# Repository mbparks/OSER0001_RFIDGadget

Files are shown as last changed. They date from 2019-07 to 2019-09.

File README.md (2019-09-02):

View this project on [CADLAB.io](https://cadlab.io/project/2087). 

# Open Source Escape Room Gadget #0001: RFID Puzzle
One of the more nifty puzzles of a great escape room is having to find objects and place them at an exact spot. Say three different candlesticks on a fireplace mantle in a specific order.

RFID tags are a great way to achieve this goal. Embedding RFID tags in the objects and RFID reader at the location the objects are to be placed.

We're building a great solution for just this puzzle concept.

The hardware includes an Arduino Uno, custom Uno shield, and dedicate PCB for 1 to 4 RFID readers to connect. While the software provided is for PN532 RFID readers using SPI communications, the hardware could be used for any RFID reader that communicates back to the microcontroller over SPI. The shield also provides for digital and analog outputs when the puzzle is unlocked. Say to activate a relay. Also an external reset is provided so escape room operators can reset the puzzle from afar.

The software requires just a few small tweaks to change from 1 to 4 RFID readers.

The source code is provided for free on GitHub and an upcoming guidebook will be available on our Gumroad store for around $5 to $10.

This design is provided as-is and no guarantees are offered. Use at your own risk.

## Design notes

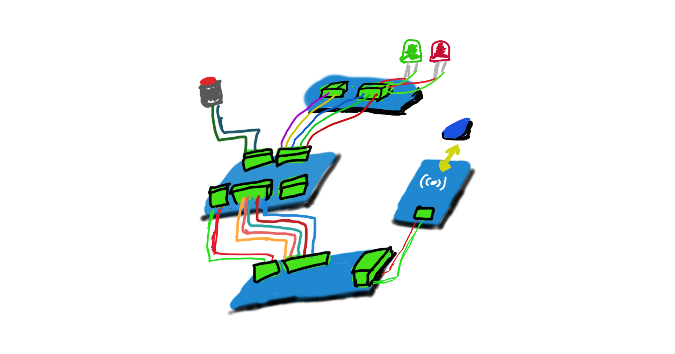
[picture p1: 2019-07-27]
Documentation/OSER0001_RFID_Concept1.png

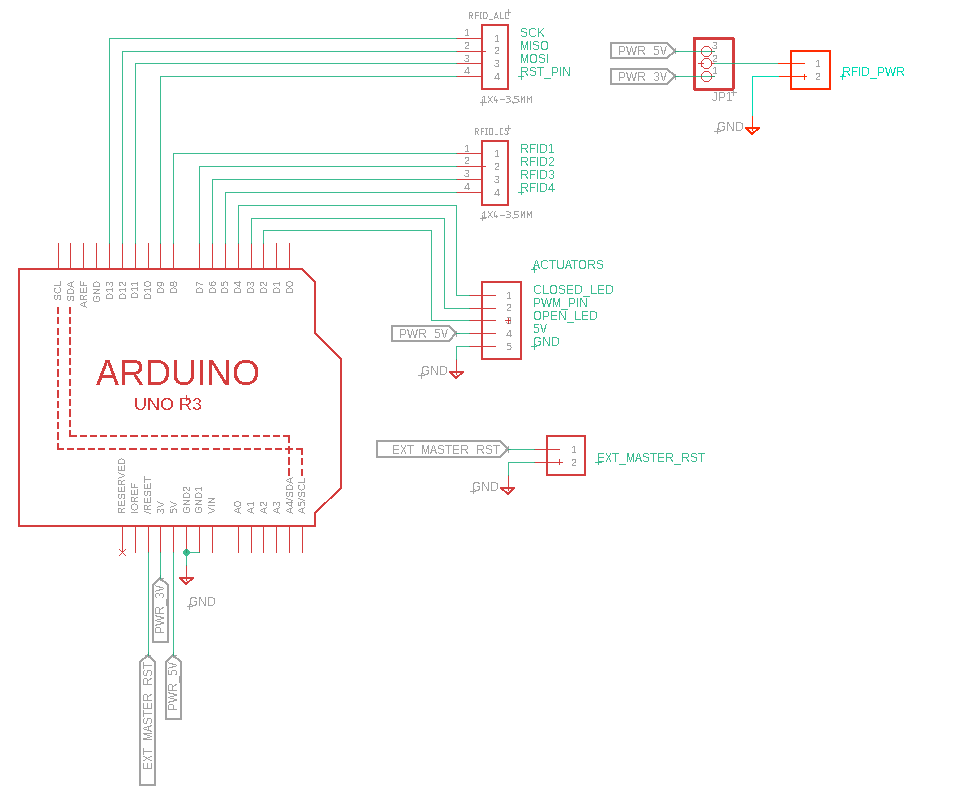
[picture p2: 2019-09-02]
Documentation/OSER0001_RFID_UnoShield_Schematic.png

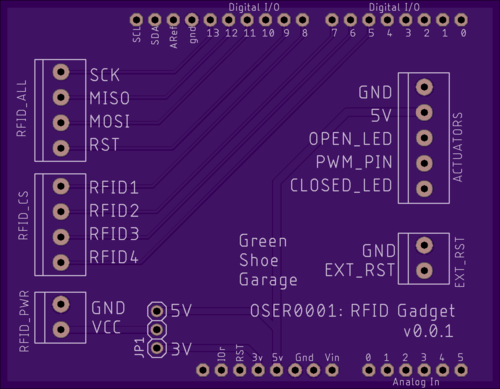
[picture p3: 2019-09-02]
Documentation/OSER0001_RFID_UnoShield_Top.png

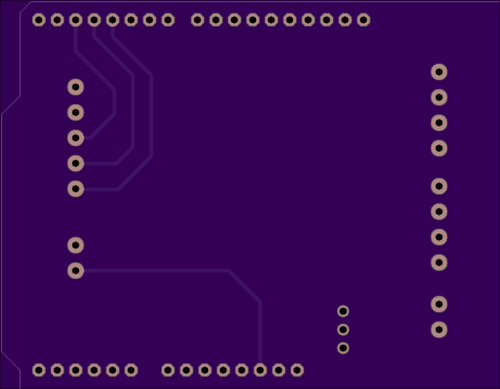
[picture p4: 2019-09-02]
Documentation/OSER0001_RFID_UnoShield_Bottom.png

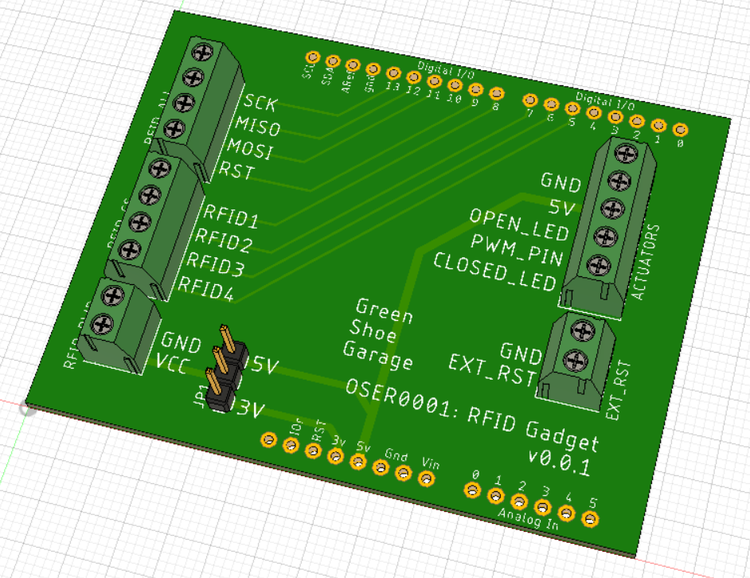
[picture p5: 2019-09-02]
Documentation/OSER0001_RFID_UnoShield_BRD3D.png

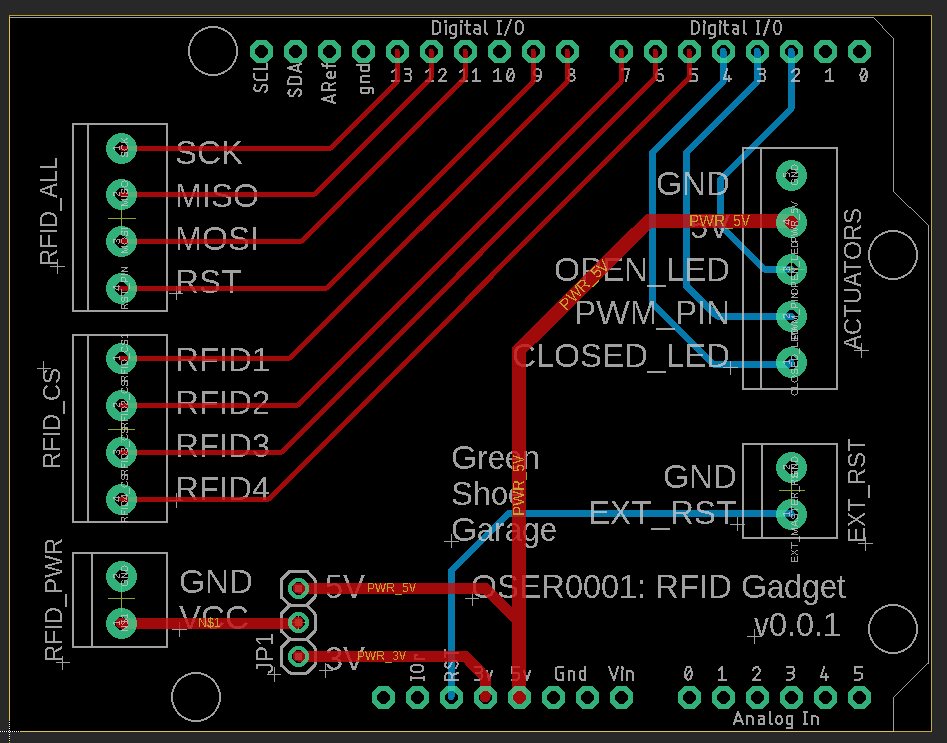
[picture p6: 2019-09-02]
Documentation/OSER0001_RFID_UnoShield_BRD.png

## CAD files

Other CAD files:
3D/OSER0001_RFID_UnoShield/OSER0001_RFID_UnoShieldPCBA/OSER_RFID_UnoShield v1.f3d

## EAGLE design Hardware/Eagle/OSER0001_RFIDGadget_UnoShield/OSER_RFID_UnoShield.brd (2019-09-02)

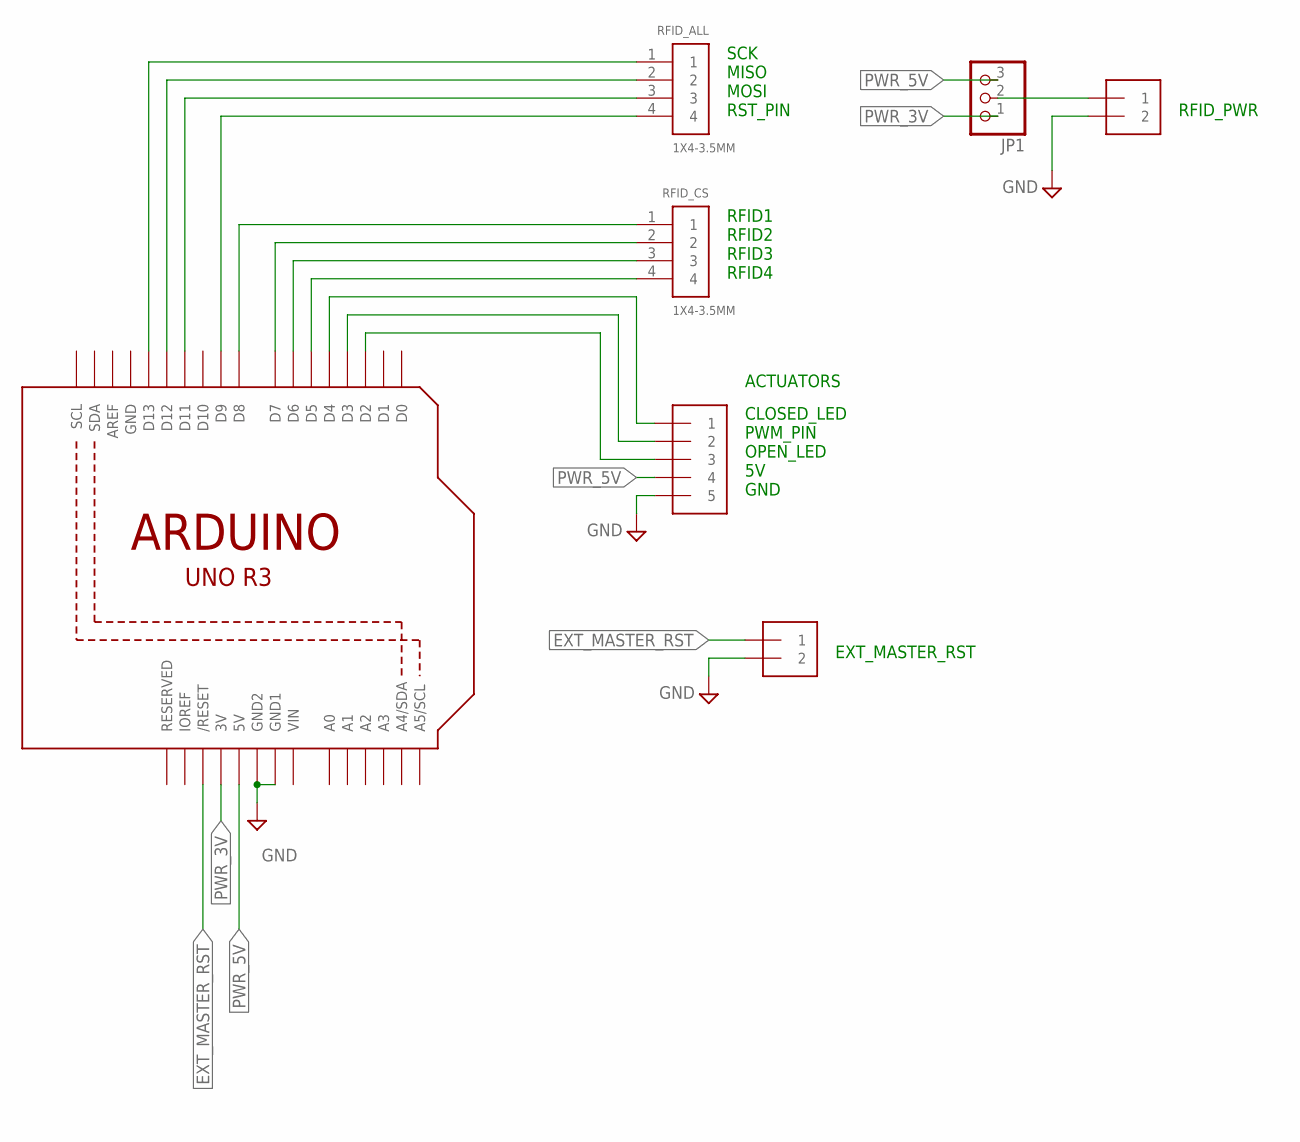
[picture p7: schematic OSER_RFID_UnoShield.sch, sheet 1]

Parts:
ACTUATORS: 1X5; 1X05-3.5MM
EXT_RST: 1X2-3.5MM
JP1: PINHD-1X3; 1X03
RFID_ALL: 1X4-3.5MM; 1X04-3.5MM
RFID_CS: 1X4-3.5MM; 1X04-3.5MM
RFID_PWR: 1X2-3.5MM
U1: ARDUINOR3-BPLACE

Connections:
CLOSED_LED: ACTUATORS.1, U1.D4
EXT_MASTER_RST: EXT_RST.1, U1.RESET (/RESET)
GND: ACTUATORS.5, EXT_RST.2, RFID_PWR.2, U1.GND, U1.GND1, U1.GND2
MISO: RFID_ALL.2, U1.D12
MOSI: RFID_ALL.3, U1.D11
unnamed: JP1.2, RFID_PWR.1
OPEN_LED: ACTUATORS.3, U1.D2
PWM_PIN: ACTUATORS.2, U1.D3
PWR_3V: JP1.1, U1.3V
PWR_5V: ACTUATORS.4, JP1.3, U1.5V
RFID2_CS: RFID_CS.2, U1.D7
RFID3_CS: RFID_CS.3, U1.D6
RFID4_CS: RFID_CS.4, U1.D5
RFID_CS1: RFID_CS.1, U1.D8
RST_PIN: RFID_ALL.4, U1.D9
SCK: RFID_ALL.1, U1.D13
VIN: U1.VIN

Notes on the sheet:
SCK MISO MOSI RST_PIN
RFID1 RFID2 RFID3 RFID4
RFID_PWR
EXT_MASTER_RST
CLOSED_LED PWM_PIN OPEN_LED 5V GND
ACTUATORS

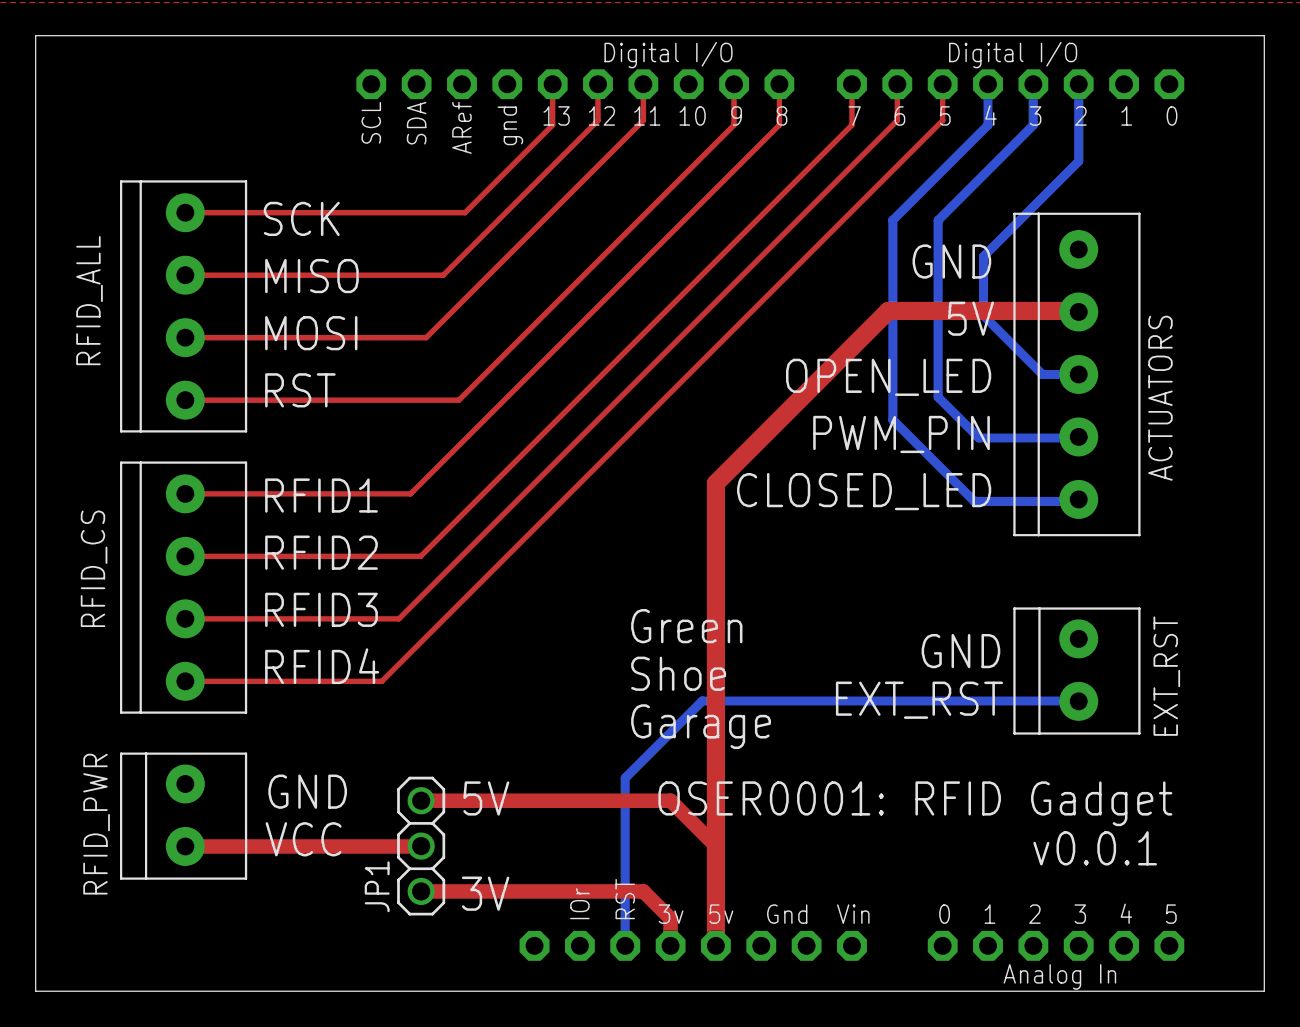
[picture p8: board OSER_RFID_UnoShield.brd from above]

Board: 2 copper layers, 68.8 x 53.5 mm, 7 parts (0 on the bottom side), 16 nets.

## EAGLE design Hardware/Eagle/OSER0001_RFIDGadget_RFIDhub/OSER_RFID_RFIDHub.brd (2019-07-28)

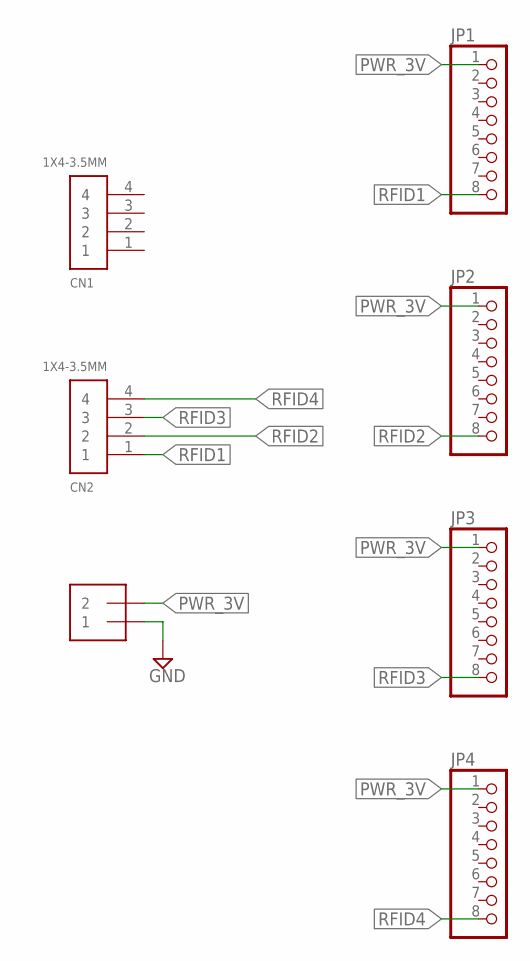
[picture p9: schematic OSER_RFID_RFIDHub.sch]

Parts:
CN1, CN2: 1X4-3.5MM; 1X04-3.5MM
J1: 1X2-3.5MM
JP1, JP2, JP3, JP4: PINHD-1X8BIG; 1X08-BIG

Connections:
GND: J1.1
PWR_3V: J1.2, JP1.1, JP2.1, JP3.1, JP4.1
RFID1: CN2.1, JP1.8
RFID2: CN2.2, JP2.8
RFID3: CN2.3, JP3.8
RFID4: CN2.4, JP4.8

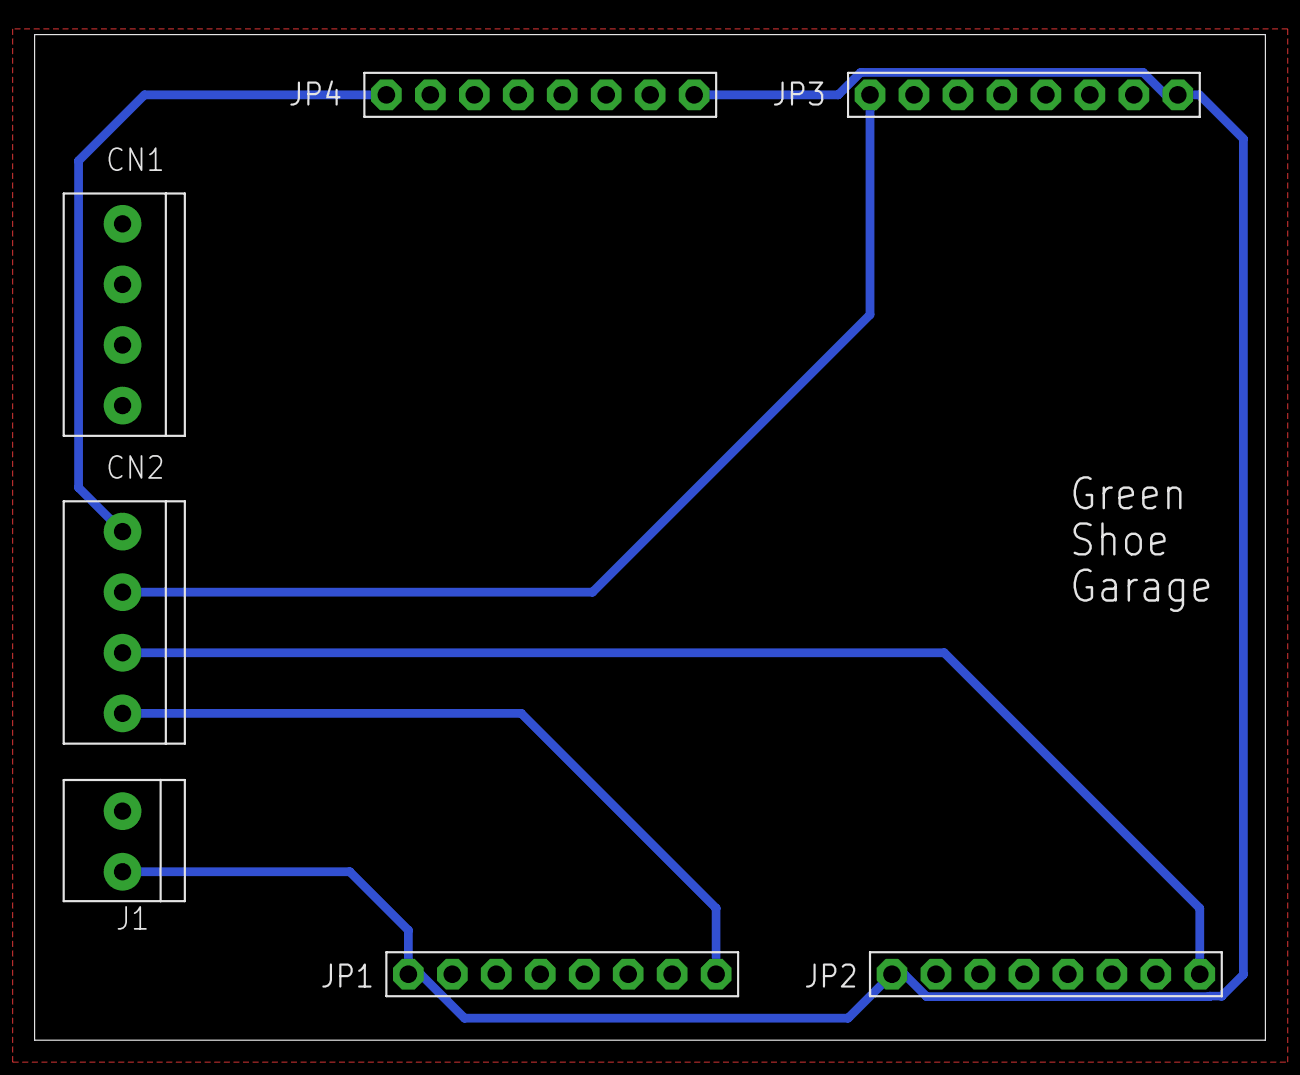
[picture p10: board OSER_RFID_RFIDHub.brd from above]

Board: 2 copper layers, 71.1 x 58.1 mm, 7 parts (0 on the bottom side), 5 nets.

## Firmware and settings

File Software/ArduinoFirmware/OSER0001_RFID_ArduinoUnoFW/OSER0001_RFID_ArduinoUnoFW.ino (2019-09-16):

/**************************************************************************
  File:    OSER0001_RFID_ArduinoUnoFW
  Author:  mbparks
  Date:    2SEP2019
  Ver.:    0.0.2
  License: MIT

  This code is four gadget that can be used in an escape room .
  It will activate a relay once all RFID tagged objects are placed
  over the correct PN532 RFID readers.
  Supports 1 through 4 RFID readers.

  Based on example code for PN532 by Adafruit Industries
  
  This is an example sketch for the Adafruit PN532 NFC/RFID breakout boards
  This library works with the Adafruit NFC breakout
  ----> https://www.adafruit.com/products/364

  Check out the links above for our tutorials and wiring diagrams
  These chips use SPI to communicate, 4 required to interface

  Adafruit invests time and resources providing this open source code,
  please support Adafruit and open-source hardware by purchasing
  products from Adafruit!

**************************************************************************/
#include <Wire.h>
#include <SPI.h>
#include <Adafruit_PN532.h>

//DEBUG message
#define DEBUG

#ifdef DEBUG
#define DEBUG_PRINT(x)  Serial.print (x)
#else
#define DEBUG_PRINT(x)
#endif

#ifdef DEBUG
#define DEBUG_PRINTLN(x)  Serial.println (x)
#else
#define DEBUG_PRINTLN(x)
#endif

const uint32_t NUM_READERS = 2;        //Adjust number as needed 1 to 4

//Hardware GPIO pin assignments
const uint32_t PN532_SCK_PIN =  13;
const uint32_t PN532_MISO_PIN = 12;
const uint32_t PN532_MOSI_PIN = 11;
const uint32_t PN532_SS1_PIN =  8;
const uint32_t PN532_SS2_PIN =  7;
const uint32_t PN532_SS3_PIN = 6;
const uint32_t PN532_SS4_PIN = 5;
const uint32_t CLOSED_LED_PIN = 4;
const uint32_t PWM_OUT_PIN = 3;
const uint32_t OPEN_LED_PIN = 2;

//The tags that will allow device to open
const uint32_t ACCEPTED_TAG_ID1 = 3872679160;
const uint32_t ACCEPTED_TAG_ID2 = 3584511166;
//const uint32_t ACCEPTED_TAG_ID3 = 0;
//const uint32_t ACCEPTED_TAG_ID4 = 0;

//PWM values for device locked (LOW) and device opened (HIGH)
const uint32_t PWM_LOW_VAL = 0;
const uint32_t PWM_HIGH_VAL = 255;

const uint32_t DELAY_AMT = 1000;
bool isLocked = true; // Init system state as locked

//An array of the chip select pins for each RFID reader
const uint32_t SS_PINS[NUM_READERS] = {PN532_SS1_PIN, PN532_SS2_PIN};  //PN532_SS3_PIN, PN532_SS4_PIN};

//An array of the accepted RFID tags for each RFID reader
const uint32_t NFC_ACCEPTED_TAGS[NUM_READERS] = {ACCEPTED_TAG_ID1, ACCEPTED_TAG_ID2};   //ACCEPTED_TAG_ID3, ACCEPTED_TAG_ID4};

//An array of RFID readers
Adafruit_PN532 *nfcReaders[NUM_READERS];


/**************************************************************************
 * Function: setup
 * Inputs:   None
 * Outputs:  None
 **************************************************************************/
void setup(void) {
  Serial.begin(115200);
  DEBUG_PRINTLN(F("Welcome to the Escape Room RFID Gadget v0.0.1!"));

  for (int x = 0; x < NUM_READERS; x++)
  {
    nfcReaders[x] = new Adafruit_PN532(PN532_SCK_PIN, PN532_MISO_PIN, PN532_MOSI_PIN, SS_PINS[x]);
    nfcReaders[x]->begin();
    //delay(DELAY_AMT*3);
    
    uint32_t versiondata = 9999;
    while (versiondata == 9999) {
      versiondata = nfcReaders[x]->getFirmwareVersion();
      DEBUG_PRINT(F("Didn't find PN53x board #"));
      DEBUG_PRINTLN(x);
    }
    
    // Got ok data, print it out!
    DEBUG_PRINT(F("Found chip PN5"));
    DEBUG_PRINTLN(String((versiondata >> 24) & 0xFF, HEX));
    DEBUG_PRINT(F("Firmware ver. "));
    DEBUG_PRINT(String((versiondata >> 16) & 0xFF, DEC));
    DEBUG_PRINT('.');
    DEBUG_PRINTLN(String((versiondata >> 8) & 0xFF, DEC));

    nfcReaders[x]->SAMConfig();
    nfcReaders[x]->setPassiveActivationRetries(1);
  }

  pinMode(PWM_OUT_PIN, OUTPUT);
  pinMode(OPEN_LED_PIN, OUTPUT);
  pinMode(CLOSED_LED_PIN, OUTPUT);

  setDeviceOutputs();

      //Device is locked and ready to go!
      DEBUG_PRINTLN(F("SUCCESS! System initialized. Waiting for RFID tags..."));
}



/**************************************************************************
 * Function: loop
 * Inputs:   None
 * Outputs:  None
 **************************************************************************/
void loop(void) {
  if (isLocked == true)
  {
    uint32_t readNfcTags[NUM_READERS];
    uint32_t countOfMatchingTags = 0;

    for (int w = 0; w < NUM_READERS; w++)
    {
      readNfcTags[w] = 0;
    }

    for (int x = 0; x < NUM_READERS; x++) {
      uint8_t success;
      uint8_t uid[] = { 0, 0, 0, 0, 0, 0, 0 };  // Buffer to store the returned UID
      uint8_t uidLength;                        // Length of the UID (4 or 7 bytes depending on ISO14443A card type)
      uint32_t cardid = 0;

      DEBUG_PRINT("READER #");
      DEBUG_PRINTLN(x);

      success = nfcReaders[x]->readPassiveTargetID(PN532_MIFARE_ISO14443A, uid, &uidLength);

      if (success) {
        // Display some basic information about the card
        DEBUG_PRINT(F("Found an ISO14443A card with "));
        //DEBUG_PRINT(F("  UID Value: "));
        //nfcReaders[x]->PrintHex(uid, uidLength);

        if (uidLength == 4)
        {
          // We probably have a Mifare Classic card ...
          cardid = uid[0];
          cardid <<= 8;
          cardid |= uid[1];
          cardid <<= 8;
          cardid |= uid[2];
          cardid <<= 8;
          cardid |= uid[3];
          //DEBUG_PRINTLN(F("Seems to be a Mifare Classic card."));
        }
      }

      DEBUG_PRINT(F("tag ID#"));
      DEBUG_PRINTLN(cardid);
      readNfcTags[x] = cardid;
      delay(DELAY_AMT);
    }

    for (int z = 0; z < NUM_READERS; z++) {
      if (readNfcTags[z] == NFC_ACCEPTED_TAGS[z])
      {
        countOfMatchingTags++;
      }
    }

    if (countOfMatchingTags == NUM_READERS) {
      activateRelay();
    }
  }
}

/**************************************************************************
 * Function: activateRelay
 * Inputs:   None
 * Outputs:  None
 **************************************************************************/
void activateRelay()
{
  DEBUG_PRINTLN(F("ALERT!!!  ALERT!!! All Tags Correct. Activate Relay.  ALERT!!! ALERT !!!"));
  analogWrite(PWM_OUT_PIN, PWM_HIGH_VAL);
  digitalWrite(OPEN_LED_PIN, HIGH);
  digitalWrite(CLOSED_LED_PIN, LOW);
  isLocked = false;
}



void setDeviceOutputs()
{
  //Warning the device is ready to lock
  DEBUG_PRINTLN("Device locking in...");
  for (int x = 3; x >= 0; x--)
  {
    digitalWrite(OPEN_LED_PIN, HIGH);
    digitalWrite(CLOSED_LED_PIN, HIGH);
    delay(DELAY_AMT);
    digitalWrite(OPEN_LED_PIN, LOW);
    digitalWrite(CLOSED_LED_PIN, LOW);
    DEBUG_PRINTLN(x);
  }

  //Initial state of outputs set
  analogWrite(PWM_OUT_PIN, PWM_LOW_VAL);
  digitalWrite(OPEN_LED_PIN, LOW);
  digitalWrite(CLOSED_LED_PIN, HIGH);
}

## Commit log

2019-07-27 init commit
    [OSER_RFID_UnoShield v1.f3d, OSER_RFID_UnoShield.brd, OSER_RFID_UnoShield.sch]
2019-07-28 hardware updates
    [OSER_RFID_RFIDHub.brd, OSER_RFID_RFIDHub.sch, OSER_RFID_UnoShield.brd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]
2019-08-30 Changed to 5V for RFID Readers
    Switched to the PN532 RFID reader which uses 5V.
    [OSER_RFID_UnoShield.brd, OSER_RFID_UnoShield.sch]
2019-08-31 Changed RFID Power to 5V
2019-08-31 Redefined SPI pins to match PCB layout
2019-08-31 Revised board silkscreen
    [OSER_RFID_UnoShield.brd]
2019-08-31 Switched to an array of pointers to Adafruit_PN532 objects
2019-09-02 1x3 header pin to allow user select 3V or 5V to RFID reader
    [OSER_RFID_UnoShield.brd, OSER_RFID_UnoShield.sch]
2019-09-02 1x3 header for 3V or 5V to the RFID board
2019-09-02 Update OSER_RFID_UnoShield v1.f3d
    [OSER_RFID_UnoShield v1.f3d]
2019-09-02 Added PWM and Digital Outputs When Correct RFID Tags presented
    [OSER0001_RFID_ArduinoUnoFW.ino]
2019-09-05 changed how to initialize readNfcTags[] array
    Use for loop instead of declaration so user doesn't need to edit code when changing the number of RFID readers used
    [OSER0001_RFID_ArduinoUnoFW.ino]
2019-09-16 uncomment SS3 and SS4 pin declarations
